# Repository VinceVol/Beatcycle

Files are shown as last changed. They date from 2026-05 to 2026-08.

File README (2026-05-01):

The goal with this bike is really to start making full sus frames using
primarily steel/ stainless steel. I've decided to start with full sus as
I already own a hardtail and don't necessarily need another.

This V1 frame is based on the starling mini murmur

The parts price/link breakout is here: https://docs.google.com/spreadsheets/d/1Qfk6l3psKUX1f9GEHReZujL-EJ3U7GY4GE1FZFarmVs/edit?usp=sharing

UDH Standards: https://www.google.com/url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

Full Frame Specs: https://www.sram.com/globalassets/document-hierarchy/frame-fit-specifications/mtb/2024-mtb-frame-fit-specifications.pdf

IS Brake Mount Specs: https://peterverdone.com/wp-content/uploads/2018/06/2019-Shimano-Disc-Brake-Standards.pdf

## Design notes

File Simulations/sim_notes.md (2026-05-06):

# FreeCad 1.1.1 FEM Learnings
Basically I've fought with setting things up in freecad to do an effective FEM so here are some of the findings

## Meshing
Export all relavent bodies to a step file.
*reopen the file and switch to Part workbench*

Use [Part -> Compound -> Compound] after reoping step file to combine all bodies into one.

*switch back to the FEM workbench* 

Netgen mesh the entire compound

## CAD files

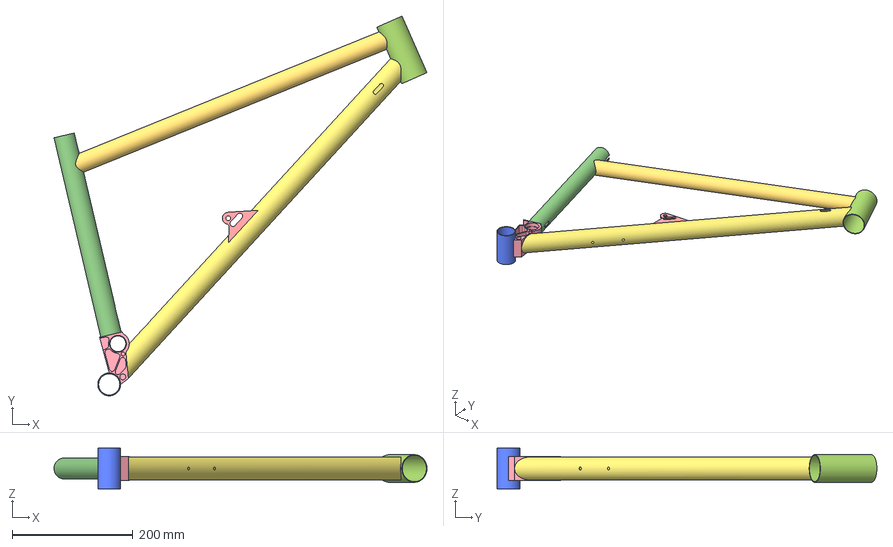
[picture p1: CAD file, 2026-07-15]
Jigs/Beatcycle-Main Triangle.step
619.0 x 630.3 x 68.0 mm
BB_Weldment
BB iso 68
SeatTube
DownTube
TopTube
HeadTube
RS_Fr_Piv

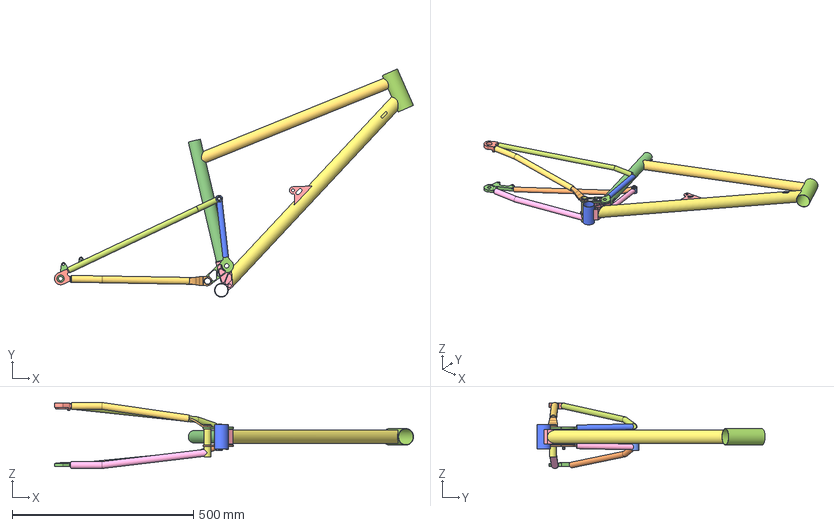
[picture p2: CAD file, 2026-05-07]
Simulations/fullframe.step
991.4 x 630.3 x 182.4 mm
BB_Weldment
BB iso 68
SeatTube
DownTube
TopTube
HeadTube
RS_Fr_Piv
Rear_Shk_Chn_lnk_1
RSCH_x_cnct
Rear_Shk_Chn_lnk_2
Yoke
UDH_DriveSide
UDH_Flat_Mnt_BrakeSide
Rear_Shock_Rear_Mnt_BrakeSide
SeatStay_BrakeSide
ChainStay_BrakeSide
MidStay_BrakeSide
SeatStay_DriveSide
ChainStay_DriveSide
MidStay_ChainSide

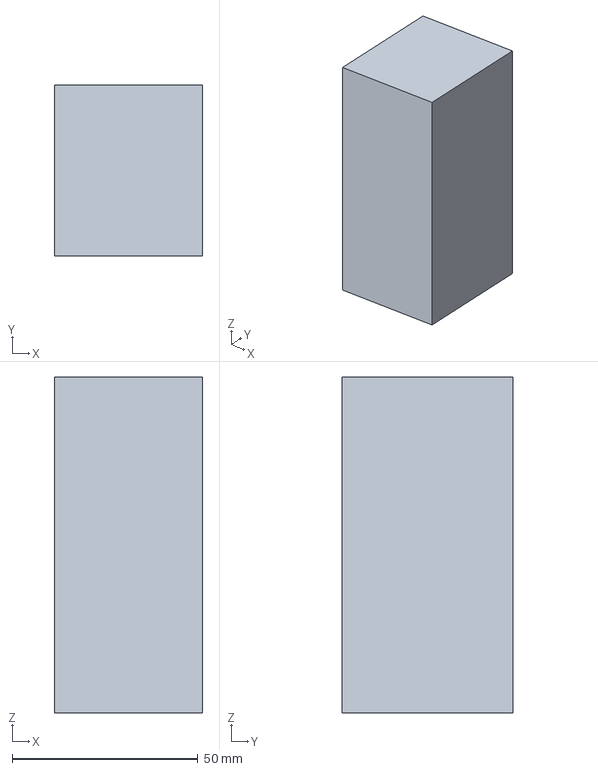
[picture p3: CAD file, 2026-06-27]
CAM Work/Main_Pivot_housing.FCStd
40.0 x 46.0 x 90.6 mm

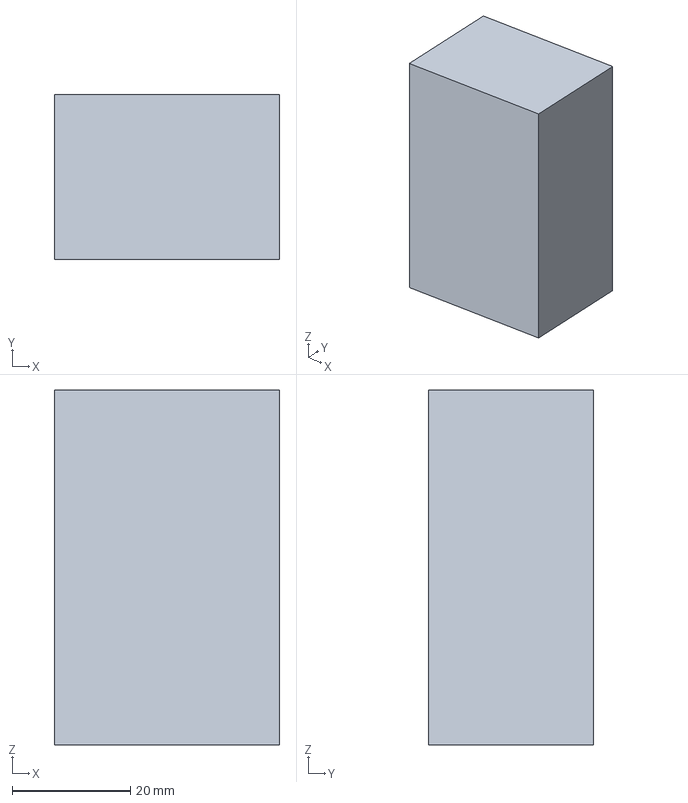
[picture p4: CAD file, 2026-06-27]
CAM Work/Front_Main_Pivot_P1.FCStd
38.1 x 27.9 x 60.0 mm

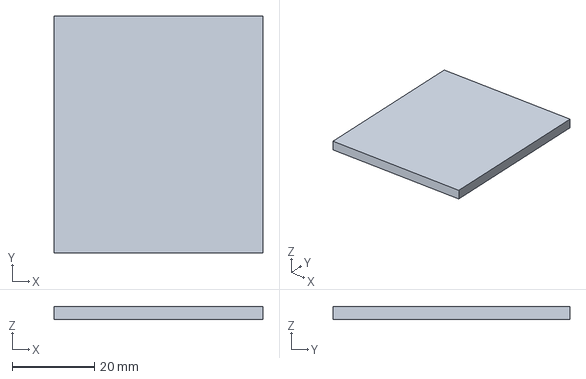
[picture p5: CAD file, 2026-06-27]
CAM Work/Front_Main_Pivot_P2.FCStd
50.8 x 57.5 x 3.17 mm

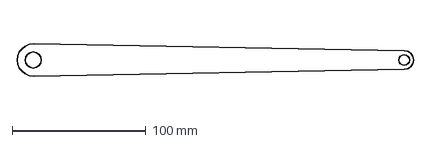
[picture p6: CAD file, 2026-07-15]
CAM Work/Alignment_Tool.dxf
296.9 x 24.2 mm

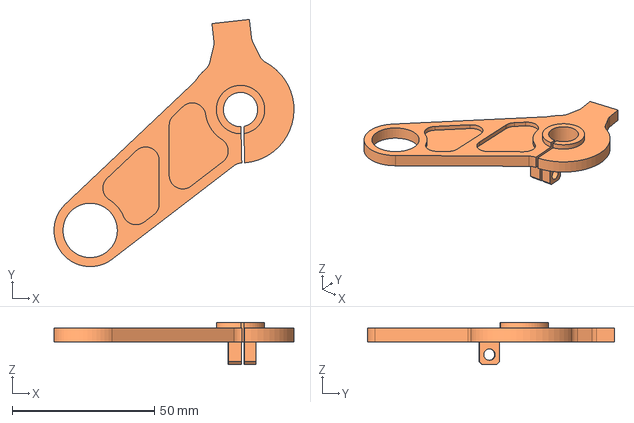
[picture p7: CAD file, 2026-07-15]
CAM Work/Step_Files/Beatcycle-Swing_ArmRear_Shk_Chn_lnk_2.step
84.3 x 86.8 x 14.8 mm

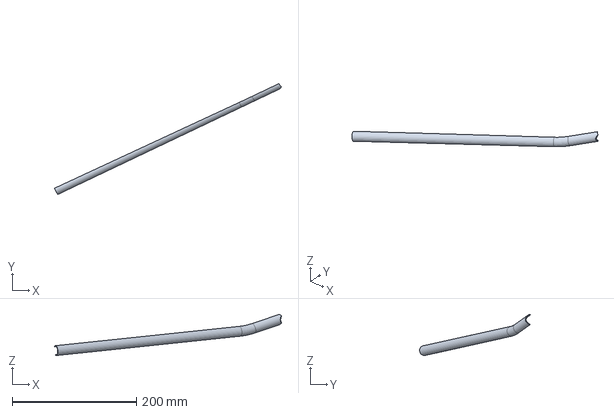
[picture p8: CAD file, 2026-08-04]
Rear_Swing_Arm_Tubing/SeatStay_BrakeSide.FCStd
365.0 x 178.2 x 66.0 mm

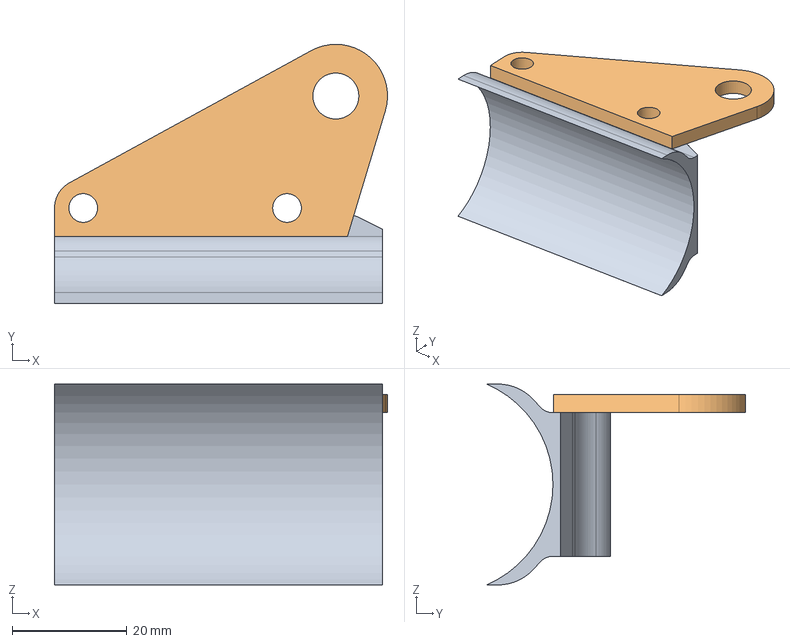
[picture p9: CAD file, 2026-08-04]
V2_FMP.FCStd
58.0 x 45.2 x 35.0 mm
Braze_On_Piece
SidePiece

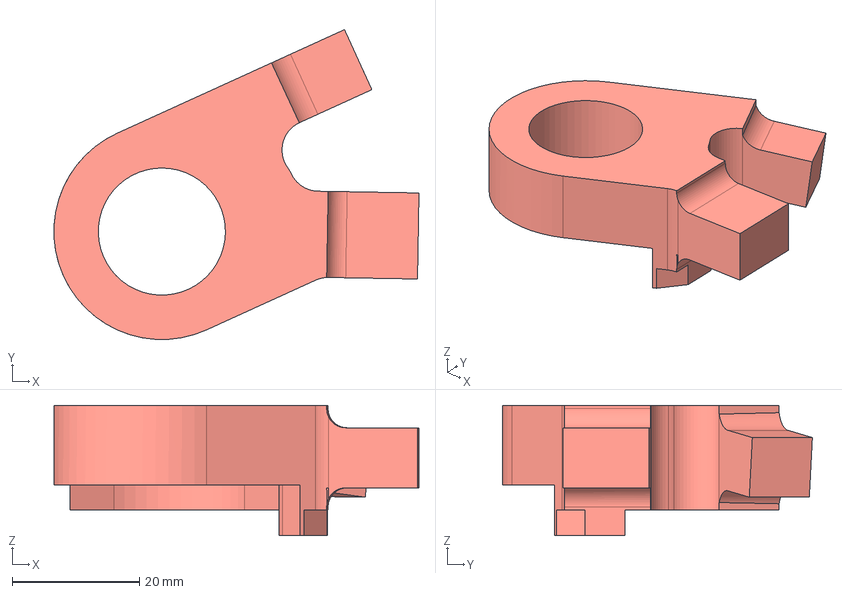
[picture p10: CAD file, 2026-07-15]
CAM Work/Step_Files/Beatcycle-Swing_ArmRear_UDH_Drive_Side.step
57.4 x 48.8 x 20.5 mm

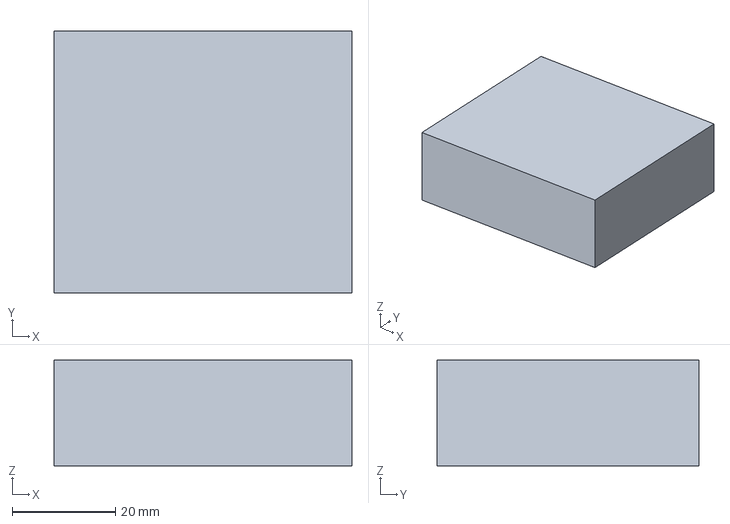
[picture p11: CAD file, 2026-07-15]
CAM Work/UDH_Drive_Side.FCStd
57.7 x 50.8 x 20.5 mm

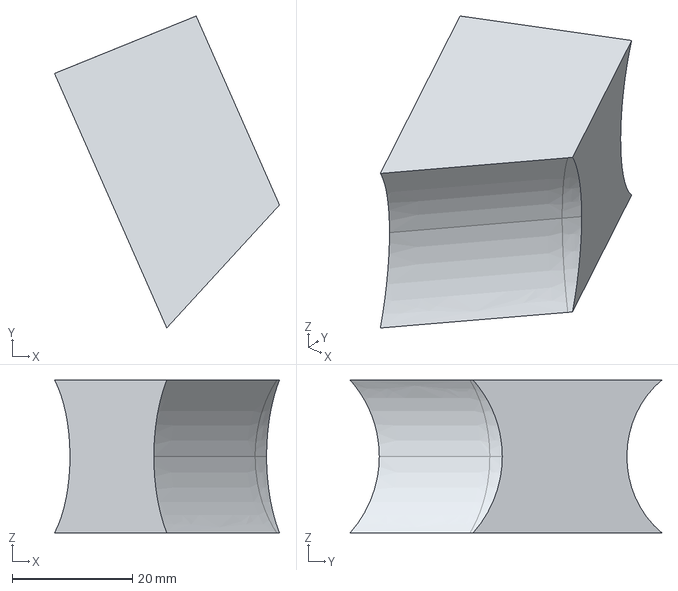
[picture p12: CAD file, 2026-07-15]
Jigs/HeadTubeReamJig-Body.step
37.4 x 51.8 x 25.4 mm

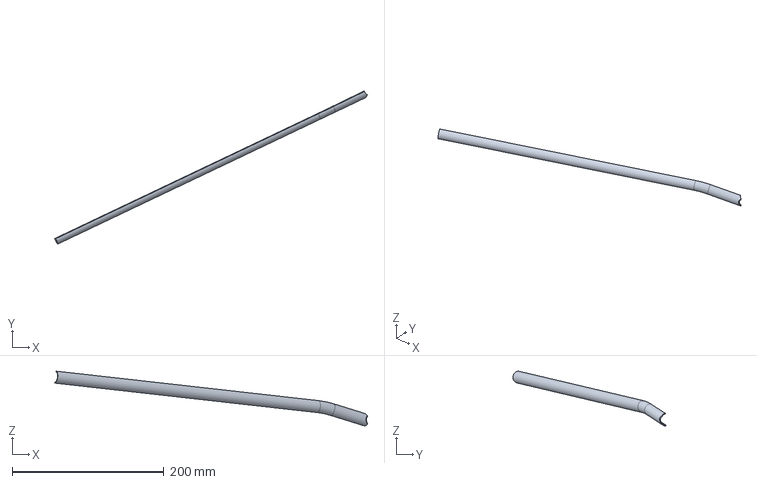
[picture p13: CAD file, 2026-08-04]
Rear_Swing_Arm_Tubing/SeatStay_DriveSide.FCStd
412.4 x 201.8 x 72.2 mm

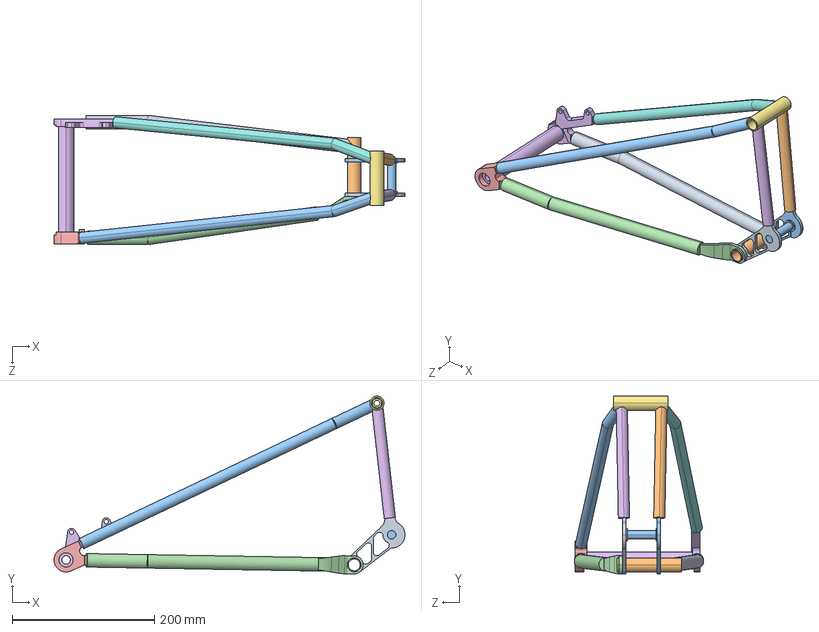
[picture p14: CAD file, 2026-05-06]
Simulations/SWRearEnd.STEP
494.3 x 250.5 x 182.4 mm
Rear_Shk_Chn_lnk_1.step
RSCH_x_cnct.step
Rear_Shk_Chn_lnk_2.step
Yoke.step
UDH_DriveSide.step
UDH_Flat_Mnt_BrakeSide.step
Rear_Shock_Rear_Mnt_BrakeSide.step
SeatStay_BrakeSide.step
ChainStay_BrakeSide.step
MidStay_BrakeSide.step
SeatStay_DriveSide.step
ChainStay_DriveSide.step
MidStay_ChainSide.step
eBom-FreeParts

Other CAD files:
Simulations/SWFullFrame.STEP
Beatcycle.FCStd
CAM Work/Beatcycle-Swing_ArmPocket050.dxf
CAM Work/Step_Files/Beatcycle-Swing_ArmRear_Shock_Rear_Mnt_BrakeSide.step
CAM Work/Downtube.dxf
CAM Work/MP_Link_1.FCStd
CAM Work/MP_Link_2.FCStd
CAM Work/R_SHK_Pivot_Weldon.FCStd
CAM Work/Rear_Shk_Chn_Link_DriveSide.FCStd
CAM Work/SidePiecePad002.dxf
CAM Work/Step_Files/Beatcycle-Swing_ArmYoke.step
CAM Work/V2_FMP_Braze_on.FCStd
CAM Work/Yoke.FCStd
CAM Work/brake_side_rear_axle.FCStd
CAM Work/drive_side_rear_axle.FCStd
Forward_Pivot_Sheet_Metal.FCStd
Forward_Pivot_pieces.FCStd
Jigs/HeadTubeReamJig-BodyPocket001.step
Jigs/HeadTubeReamJig.FCStd
Outside Parts/2349K413_Permanently Lubricated Ball Bearing.STEP
Rear_Swing_Arm_Tubing/BrakeSide_Cuts.dxf
Rear_Swing_Arm_Tubing/BrakeSide_Swing_Arm_Vert.dxf
Rear_Swing_Arm_Tubing/ChainStay_BrakeSide.FCStd
Rear_Swing_Arm_Tubing/ChainStay_BrakeSide.dxf
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

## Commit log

2026-04-21 first commit with previous work, mostly starting with stirling mini murmur base geo stick figure
    [Beatcycle.FCStd, Beatcycle_hummingbird_Dinner_Fork.FCStd]
2026-04-21 -Realized the image I was copying was actually the murmur *despite the image coming from mini murmur site* so found an actual image of the mini murmur and made slight tweaks to get to that. Other tha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
    -Started working on the BB CNC part that connects the seat tube, down tube, BB and main pivot. Basing things around the 6902-2RS bearing platform.
    --Need to determin if there is some kind of required bushing for the side to side play, these bearings are radial load
    [Beatcycle.FCStd]
2026-04-22 -Added a README to point out the parts list with links in google sheets -Reworked the BB Weldment to be a bit thinner and to hold the seat tube on center. This should help locate the weldment during 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
    [2901 2RS Bearing.STEP, Beatcycle.FCStd]
2026-04-22 -Enlarged the surface to weld the seat tube to the BB weldment -Added the BB -Added the seat tube -Added the down tube
    Overall Main triangle is what is being worked on
    [Beatcycle.FCStd]
2026-04-23 -Finished up some of the main triangle details --Missing a seat clamp weldon --Missing some sort of component to hold cables in place
    -Almost ready to work on rear linkage
2026-04-24 -Working on rear pivoting assembly.
    --Looking at using a shoulder bolt as the main pivot
    --mainly spent time searching for the best way to do the main pivot.
    -Updated the main pivot bearings to be 6001-2RS
    -Changed the front rear shock pivot width to 25mm (sincethe shock came with that)
2026-04-28 -Fighting to determine the best way to do this rear pivot bit where the main main pivot connects to the chainstays --Thinking some combination of machine -> weld -> machine so that things maintain th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
2026-04-28 -Progressed the main pivot -> chainstay/rear shock rear mount linkage piece -Somewhat settled on using 3/4 chainstay tubing to bridge the linkages -Once full rear linkage design done, wanting to comp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
    [2349K413_Permanently Lubricated Ball Bearing.STEP, 2901 2RS Bearing.STEP]
2026-04-28 Started working on the opposite side for the previous commit -Finding that it might be smarter to post weld on a piece to allow for the clamping action rather than building it into the CNC'd 4.7mm th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
    [Beatcycle.FCStd]
2026-04-29 -Still working through the details surrounding the main pivot. --Starting to account for front chainring as well as tire clearance around the yoke and other pivoting components in that area. --Still 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
    [Beatcycle.FCStd]
2026-04-30 -Started working through UDH rear axle alongside the post mount (since we ofcourse chose a postmount rear brake) -Post mount rear is giving me some annoying issues
    -Linked in the README to SRAM frame references for everything
2026-04-30 -Switched to post mount rear brake as it would've been hard to fit the lat mount brake in -Having issues doing complicated surfacing to make the post mounts pretty
2026-04-30 -Worked on refining the UDH and trying to get the post mount functional. -Changed the seat stay to bend to follow the chainstay (need to fix so it bends to follow the seatstay) -Need to creat a seats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
    -Unfortunately still need to wrap up the actual post mount -- hopefully wont take more than an hour rip
    [Beatcycle.FCStd]
2026-05-01 -Realized the IS mounting standard was a thing and opted to go that route instead since for my rear brake I was going to need adapters regardless -Need to thicken the brake portion from 4 -> 7 mm via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
2026-05-01 Finally wrapped up the rear IS brake mount -Started working on rear shock hookup point -Getting stuck on 3 dimensional drawings and getting the bent seat/chainstays drawn
2026-05-01 -Added chainstay and seatstay tubing on the brake side -Need to change the chainstay master to have a longer flat section although it looks like this may take some time as many things break when I do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
    sad
    [Beatcycle.FCStd]
2026-05-01 Working through the chainstay movement, unfortunately having to redraw a lot as a lot broke -Something we need to figure out is centering the rear wheel based on the UDH mount, I'm a bit confused as 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
2026-05-02 -Fixed the rear axle centerline and redrew the yoke 50 times for it -Tried to simplify chain and seat stay bends by moving things around
2026-05-04 Finished drawing up the untested frame -Need to run an FEA and likely just beef up the two swing arms connecting to the main pivot (they're looking a bit thin) -Not sure yet what to compare to but ma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
2026-05-06 Learned a bit more about freecad FEM -Generally speaking the freecad step export and then reimporting into freecad combining bodies and generating a mesh is causing some weird artifacts. -For now use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
    [BeatcycleV1.FCStd, SWFullFrame.STEP, SWRearEnd.STEP]
2026-05-07 -Beefed up the linkage as seen somewhat fit and moving on git commit -m
    [fullframe.step]
2026-05-15 Updated front triangle to account for ZS44/EC44 headset -- basically moved the head tube to match the image given that starling is using the same headset
    [Rear_Shk_Chn_Link_DriveSide.FCStd]
2026-05-18 -Updated the chainstays to account for pedal clearance -Updated chain/seat stays to account for 3in bend radius
2026-05-19 -Removed old hummingbird stuff -Updated chainstay bends to be matching the ordered die
    [Beatcycle.FCStd, Beatcycle_hummingbird_Dinner_Fork.FCStd]
2026-05-26 -Working to figure out how to get some of these parts made of sheet metal --Starting with the forward pivot on the rear shock
    [Beatcycle.FCStd, Forward_Pivot_Sheet_Metal.FCStd, Main_Pivot_housing.FCStd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]
2026-05-26 -Didn't achieve much -- Basically looking to weld on two tabs that'll hold the front of the rear shock in place. --no riv nuts, just a shoulder bolt with a locknut on the back -- unsure about rigidit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
    [Beatcycle.FCStd, Forward_Pivot_Sheet_Metal.FCStd]
2026-05-27 -Tried a variant of the rear shock front mount using bent chromoly tubing, realized it sticks too far in front of the knees and is likely harder to make than the heavily machined block
    [Beatcycle.FCStd, Forward_Pivot_Sheet_Metal.FCStd]
2026-06-01 -Broke up the forward pivot into a couple more machineable pieces --Should have the added benefit of being able to move the pivot point if needed
    [Forward_Pivot_pieces.FCStd]
2026-06-27 making progress but redesigning front rear shock mount as it caused 2 broken taps and 2 broken drill bits for the M3s, redesigning for M5s... quite the bummer
    [Beatcycle.FCStd, Forward_Pivot_pieces.FCStd, Front_Main_Pivot_P1.FCStd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]
2026-07-15 working on some more cam -- rear swing arm and UDH components
    [Alignment_Tool.dxf, Beatcycle-Main Triangle.step, Beatcycle-Swing_ArmPocket050.dxf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]
2026-07-15 Added the chainstay brakeside drawings and template
    [ChainStay_BrakeSide.FCStd]
2026-07-16 Tubing drawings work
    [ChainStay_DriveSide.FCStd]
2026-08-04 some FMP edits
    [BrakeSide_Cuts.dxf, BrakeSide_Swing_Arm_Vert.dxf, ChainStay_BrakeSide.dxf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]
